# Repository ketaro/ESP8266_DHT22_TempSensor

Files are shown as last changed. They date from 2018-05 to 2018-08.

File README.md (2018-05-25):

# ESP8266 + DHT22 Temp Sensor

Arduino code, assets, and 3d-printable case for a basic wifi-enabled temperature sensors.

Some things to get you started:

* CH340 Chipset Driver
  *  https://github.com/adrianmihalko/ch340g-ch34g-ch34x-mac-os-x-driver

* Add Board Manager URL in Arduino IDE
  * http://arduino.esp8266.com/stable/package_esp8266com_index.json

* Plugin for uploading SPIFFS
  * https://github.com/esp8266/arduino-esp8266fs-plugin

* Web Server / SPIFFS inspired by
  * https://circuits4you.com/2018/02/03/esp8266-nodemcu-adc-analog-value-on-dial-gauge/

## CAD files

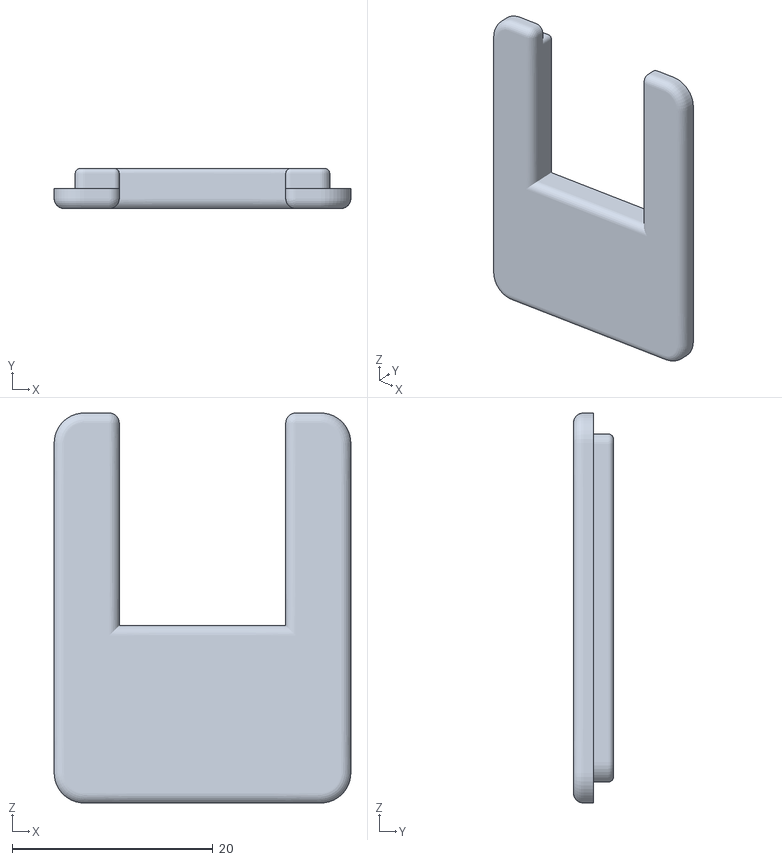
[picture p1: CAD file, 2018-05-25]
case/esptemp_lid_final_nolatch_v2.stl
29.6 x 4.00 x 38.9

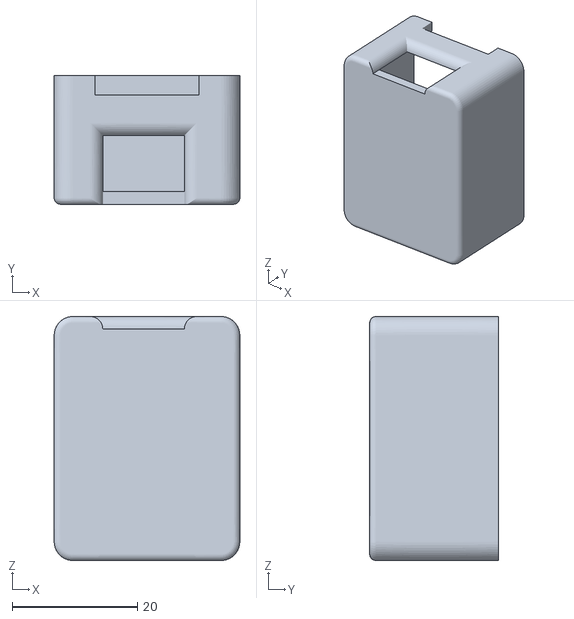
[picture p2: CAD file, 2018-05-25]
case/esptemp_body_final_nolatch_v6.stl
29.6 x 20.5 x 38.9

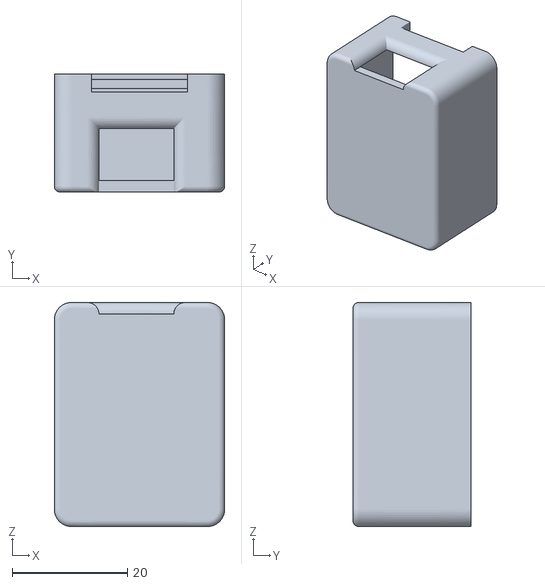
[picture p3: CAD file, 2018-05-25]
case/esptemp_body_final_v6.stl
29.6 x 20.5 x 38.9

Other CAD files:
case/esptemp_lid_final_v2.stl

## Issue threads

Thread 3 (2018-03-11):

Webserver doesn't work when device is in AP mode

ketaro, 2018-03-11:
For example, after a factory reset, webserver seems to only be able to server a partial request before the device wedges.

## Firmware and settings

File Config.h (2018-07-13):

//
// config.h - Library for handling storing and retrieving 
//            config settings from EEPROM
//

#ifndef Config_h
#define Config_h

#include "Arduino.h"
#include "defaults.h"

#define CONFIG_VERSION           5
#define EEPROM_SIZE              512
#define EEPROM_CONFIG_START      0

#define DEFAULT_HOSTNAME         "esp-dht-1"
#define DEFAULT_HTTP_PORT        8080
#define DEFAULT_SAMPLE_INTERVAL  60
#define DEFAULT_SSID             "SightUnseenFarm"
#define DEFAULT_WIFI_PW          "PASSWORD"        // Also the default AP password
#define DEFAULT_HTTP_PW          "admin"
#define DEFAULT_T_OFFSET         0

#define CONFIG_HOSTNAME        1
#define CONFIG_LOCATION        2
#define CONFIG_HTTP_PW         3
#define CONFIG_SSID            10
#define CONFIG_WIFI_PW         11
#define CONFIG_DB_HOST         20
#define CONFIG_DB_PORT         21
#define CONFIG_DB_NAME         22
#define CONFIG_DB_MEASUREMENT  23
#define CONFIG_SAMPLE_INTERVAL 24
#define CONFIG_T_OFFSET        25
#define CONFIG_DB_TYPE         26

#define MAX_HOSTNAME  20
#define MAX_LOCATION  20
#define MAX_HTTP_PW   10
#define MAX_SSID      32
#define MAX_WIFI_PW   32
#define MAX_DB_HOST   64
#define MAX_DB_NAME   20
#define MAX_DB_MEASUREMENT 20

// Database Types
#define DB_TYPE_NONE       0
#define DB_TYPE_INFLUXDB   1
#define DB_TYPE_HTTP       2


//
// EEPROM Configuration Structure
struct configuration {
  unsigned int version;

  // System Settings (and +1 for the \0)
  char hostname[ MAX_HOSTNAME+1 ];
  char location[ MAX_LOCATION+1 ];
  unsigned short http_server_port;
  char http_pw[ MAX_HTTP_PW+1 ];

  // Network Settings
  char ssid[ MAX_SSID+1 ];
  char wifi_pw[ MAX_WIFI_PW+1 ];

  // Database Settings
  byte           db_type;             // 0 - none, 1 - influxdb, 2 - http
  char           db_host[ MAX_DB_HOST+1 ];
  unsigned short db_port;
  char           db_name[ MAX_DB_NAME+1 ];
  char           db_measurement[ MAX_DB_MEASUREMENT+1 ];  // Measurement string

  unsigned int sample_interval;

  // Temperature offset
  float t_offset;

};


//
// Config Library Class
class Config
{
  public:
    Config();
    void readConfig();
    bool set( int key, String value );
    void writeConfig();
    void resetConfig();

    void reboot();

    String JSON(String macaddr);

    configuration conf;


  private:
    configuration _defaults = { CONFIG_VERSION, DEFAULT_HOSTNAME, "unknown", DEFAULT_HTTP_PORT, DEFAULT_HTTP_PW,
                                DEFAULT_SSID, DEFAULT_WIFI_PW,
                                DB_TYPE_INFLUXDB, "influxdb", 8086, "temp", "ambient", DEFAULT_SAMPLE_INTERVAL  };    

};


#endif

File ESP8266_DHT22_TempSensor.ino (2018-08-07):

/*
 *  ESP8266+DHT22 Temperature Sensor
 *  Nick Avgerinos - http://github.com/ketaro
 *  Tyler Eaton - https://github.com/googlegot
 *
 * - - - - - - - - - - - - - - - - - - - - - - - - - - - - - - - - - - - - - - - - -
 *
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
 * - - - - - - - - - - - - - - - - - - - - - - - - - - - - - - - - - - - - - - - - -
 *
 *  CH340 Chipset Driver (for OSX)
 *  https://github.com/adrianmihalko/ch340g-ch34g-ch34x-mac-os-x-driver
 *
 *  Add Board Manager URL in Arduino IDE
 *  http://arduino.esp8266.com/stable/package_esp8266com_index.json
 *
 *  Plugin for uploading SPIFFS
 *  https://github.com/esp8266/arduino-esp8266fs-plugin
 *
 *  Web Server / SPIFFS inspired by:
 *  https://circuits4you.com/2018/02/03/esp8266-nodemcu-adc-analog-value-on-dial-gauge/
 * 
 *  OTA Update
 *  http://esp8266.github.io/Arduino/versions/2.0.0/doc/ota_updates/ota_updates.html
 *
 *  DoubleResetDetector
 *  https://github.com/datacute/DoubleResetDetector
 */

#include <ESP8266mDNS.h>
#include <ESP8266HTTPClient.h>

#include "defaults.h"
#include "Config.h"
#include "Network.h"
#include "Sensor.h"
#include "DB.h"
#include "Webserver.h"


//
// Helper Classes
Config config;
Network net;
DB db;
Sensor sensor(DHTPIN, DHTTYPE);
Webserver web;


//
// GLOBALS
//
int send_to_db_interval    = 30000;    // 30 seconds
int next_send_to_db        = send_to_db_interval;


//
// A R D U I N O  S E T U P
void setup() {
  delay(1000);
  
  // Start serial
  Serial.begin(115200);
  Serial.println();

  Serial.println("---------------------------");
  Serial.println("HEATSTROKE INO: " + String(INO_VERSION));
  Serial.println("---------------------------");
  Serial.println();
 
  // Initialize Network/WiFi
  net.begin( &config );

  // Start the temperature sensor
  sensor.begin( &config );

  // Initialize the database library
  db.begin( &config, &sensor );
  send_to_db_interval = config.conf.sample_interval * 1000;

  // Initialize File System and Web Server
  web.begin( &config, &sensor, &db );
  delay(500);
}


// Main Arduino Loop
void loop() {
  sensor.loop();
  net.loop();
  web.loop();

  if (millis() > next_send_to_db) {  // Time to send readings to the db
    if ( net.connected() ) {  // Can't send if we're not connected
      db.send();
    } else {
      Serial.println("[NO NETWORK] Cannot send to DB.");
    }
    next_send_to_db = millis() + send_to_db_interval;
  }

  if ( millis() > MAX_RUNTIME ) {
    // If we've been running more than MAX_RUN, just reboot to reset
    // millis() so we don't have to deal with overflow
    Serial.println( "----------------------------------" );
    Serial.println( "MAX RUNTIME REACHED, RESTARTING..." );
    Serial.println( "----------------------------------" );
    ESP.restart();
  }

}

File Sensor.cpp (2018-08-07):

//
// Sensor.cpp - Library for handling readings from the temp sensor.
//

#include <DHT.h>

#include "Sensor.h"
#include "defaults.h"


//Sensor::Sensor(uint8_t pin, uint8_t type) {
//  Serial.println("[Sensor] DHT(" + String(pin) + ", " + String(type) + ")");
//  _dht = DHT(pin, type);
//};


void Sensor::begin( Config *config ) {
  // Keep a reference to the config
  _config = config;
  _poll_sensor_interval = SENSOR_POLL_INTERVAL * 1000;
  _next_sensor_poll = millis() + _poll_sensor_interval;

  sensor_on();
  _dht.begin();
}


void Sensor::loop() {
  if (millis() > _next_sensor_poll) {   // Time to read the sensors
    read_sensor();
    _next_sensor_poll = millis() + _poll_sensor_interval;
  }
}


// Main Sensor Turn On
void Sensor::sensor_on() {
  pinMode(DHTPWR, OUTPUT);
  digitalWrite(DHTPWR, 1);
}


// Try to reset the DHT sensor.  This only works if your
// sensor is wired to use the DHTPWR pin
void Sensor::reset_sensor() {
  Serial.println("Resetting Sensor...");

  digitalWrite(DHTPWR, 0);
  delay(500);
  digitalWrite(DHTPWR, 1);

  // Give the sensor a cooling off by skipping the next interval
  _next_sensor_poll = millis() + _poll_sensor_interval*2;
//  delay(SENSOR_DELAY_AFTER_RESET);
  
  _dht.begin();
}

// Reading Getters
float Sensor::get_temp()     { return _cur_temp; }
float Sensor::get_humidity() { return _cur_humidity; }
float Sensor::get_hindex()   { return _cur_hindex; }
float Sensor::get_analog()   { return _cur_analog; }
float Sensor::get_pressure() {
  if (_cur_analog)
    return ((_cur_analog / 1024) * 200) - 3.35; // dirty offset removal  
  return NAN;
}


// Attempt to read sensor values from the DHT22
void Sensor::read_sensor() {
    Serial.println("[Sensor] read_sensor");

    // Subtract the temperature offset due to heating from the MCU
    float temp     = _dht.readTemperature(true) - _config->conf.t_offset;
    float humidity = _dht.readHumidity();

    if (isnan(temp) || isnan(humidity)) {
      // Successfully failed to get a readout from the DHT22
      Serial.println("[Sensor] Failed to get reading from DHT22");

      // If we haven't got a reading in SENSOR_RESET_INTERVAL, reset the sensor
      if (millis() - _last_sensor_read > SENSOR_RESET_INTERVAL * 1000) {
        reset_sensor();  // may the odds be ever in your favor.
        _last_sensor_read = millis();   // not really, but set the counters based off now

        // Clear out current readings
        _cur_temp     = NAN;
        _cur_humidity = NAN;
        _cur_hindex   = NAN;
      }

    } else {
      // Successfully got a readout
      _last_sensor_read = millis();
   
      _cur_temp     = temp;
      _cur_humidity = humidity;
      _cur_hindex   = _dht.computeHeatIndex(temp, humidity);

      // Write out to serial
      Serial.println("[Sensor] Temp: " + String(_cur_temp, 2) + "F   " 
                    "Humidity: " + String(_cur_humidity, 2) + "%   "
                    "Heat Index: " + String(_cur_hindex, 2));
    }

    // Calculate Pressure
    read_analog();
}


// Sample the analog sensor
void Sensor::read_analog() {
  uint16_t sum = 0;
  for(int i=0; i < 64; i++) {
    delay(5);
    sum += analogRead(PRESSURE_PIN);
  }
  _cur_analog = float(sum) / 64.0;
  Serial.println("[Sensor] Analog Sensor: " + String(_cur_analog));
}

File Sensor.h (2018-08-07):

//
// Sensor.h - Library for handling readings from the temp sensor.
//

#ifndef Sensor_h
#define Sensor_h

#define DHT_DEBUG
#include <DHT.h>
#include "defaults.h"
#include "Config.h"

#define SENSOR_POLL_INTERVAL     10    // Seconds
#define SENSOR_RESET_INTERVAL    60    // Reset the sensor if it's been at least this many
                                       // seconds since we last got a successful reading

//
// Sensor Library Class
class Sensor
{
  public:
    Sensor(uint8_t pin, uint8_t type): _dht(pin, type) { };

    void begin( Config *config );
    void loop();

    void sensor_on();
    void read_sensor();
    void read_analog();
    void reset_sensor();
    
    float get_temp();
    float get_humidity();
    float get_hindex();
    float get_analog();
    float get_pressure();
    
  private:
    Config     *_config;
    DHT        _dht;
//    DHT        _dht(DHTPIN, DHTTYPE);

    int _poll_sensor_interval   = SENSOR_POLL_INTERVAL * 1000;    // Read the sensors every 10 seconds
    int _next_sensor_poll       = _poll_sensor_interval;

    unsigned long _last_sensor_read = 0;
    float _cur_temp       = NAN;
    float _cur_humidity   = NAN;
    float _cur_hindex     = NAN;
    float _cur_analog     = NAN;

};

#endif

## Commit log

2018-03-28 Missing some parens - the soft AP wasnt starting without them
    [ESP8266_DHT22_TempSensor.ino]
2018-03-28 Setting WiFi.mode() to WIFI_AP after failed attempts at wifiConnect. Seems to make softap much much more reliable. Docs seem to indicate that WiFi.mode(WIFI_STA) should preent ap from working at all.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
    [ESP8266_DHT22_TempSensor.ino]
2018-04-30 Added a 3d-printable case
    [esptemp_body_final_nolatch_v6.stl, esptemp_body_final_v6.stl, esptemp_lid_final_nolatch_v2.stl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]
2018-04-30 Added note about case model
2018-05-09 more config setting fixes; OTA update
    [Config.cpp, Config.h, ESP8266_DHT22_TempSensor.ino]
2018-05-10 web ui: alert box, disable buttons when saving
2018-05-14 Added temperature offset...stuff
2018-05-14 complete t_offset saving from config form. Fix fallback AP/PW not getting set.
    [Config.cpp, Config.h, Network.cpp]
2018-05-22 breakout Sensor handler into it's own library.
2018-05-22 fix how pointers were being passed
    [DB.cpp, ESP8266_DHT22_TempSensor.ino, Network.cpp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]
2018-05-22 Added level shifting PCB fritzing project and gerber files what for making the sensor run at 5v
    [Wemos_DHT22_Levelshifter.fzz]
2018-05-23 Fixed PCB layout errors
2018-06-18 Slight PCB update, final design
    [Wemos_DHT22_Levelshifter.fzz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]
2018-06-18 Added silkscreen text to board to indicate orientation and sensor location
    [Wemos_DHT22_Levelshifter.fzz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]
2018-06-18 Updated capacitor silkscreen to correct value
    [Wemos_DHT22_Levelshifter.fzz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]
2018-06-28 Added Honeywell 19C200PA5K sensor board PCB
    [Honeywell_19C_Wemos.fzz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]
2018-06-28 Moved gerber files into board-specific directory
    [Wemos_DHT22_Levelshifter_contour.gm1, Wemos_DHT22_Levelshifter_copperBottom.gbl, Wemos_DHT22_Levelshifter_copperTop.gtl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]
2018-06-28 Renamed Honeywell board to match DHT22 board naming convention, added a decoupling capacitor to the voltage regulator on the Honeywell board, and added gerber files for Honeywell 19C board
    [Honeywell_19C_Wemos.fzz, Wemos_Honeywell_19C.fzz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]
2018-07-18 Additional testing indicates the need for common mode rejection and signal amplification with a pot for gain control.
    [Wemos_Honeywell_19C.fzz]
2018-07-18 Updated gerber file, reduced PCB size
    [Wemos_Honeywell_19C.fzz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]
2018-07-18 Added 7812 voltage regulator on input as well for sensor stability
    [Wemos_Honeywell_19C.fzz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]
2018-07-18 Switched to more common DC jack/trim pot style, minor layout changes.
    [Wemos_Honeywell_19C.fzz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]
2018-08-02 Removed reverse voltage protection diode (too much voltage drop at 12v) and current limited the voltage regulator zener through the 100 ohm resistor to ground.
    [Wemos_Honeywell_19C.fzz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]
2018-08-02 Switched to conventional DC jack design
    [Wemos_Honeywell_19C.fzz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]
2018-08-07 working on spiffs http update. Initial test analog sensor readings.
2018-08-07 Switched to float math for adc -> psi conversion, added janky offset for now, moved to uint16_t for pressure sensor accumulator to implement increase to 64 sample averaging
    [Wemos_Honeywell_19C.fzz]
